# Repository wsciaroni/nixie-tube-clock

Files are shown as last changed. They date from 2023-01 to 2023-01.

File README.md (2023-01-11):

# nixie-tube-clock
Work in progress for designing and building a custom Nixie Tube Clock

## Starting Point

This project is incomplete.

I have started from the really helpful blog here: https://crystal.uta.edu/~burns/project_nixieclock.html

## Overview

I remember my first exposure to Nixie Tubes vividly. It was an old coin counting machine we were using for a change colection fund raiser. I was fascinated by the Nixie Tubes and have never forgotten them.

After observing many other Nixie Clock builds, I decided there wasn't one that met all of my needs.

The closest that I found was here: https://crystal.uta.edu/~burns/project_nixieclock.html. However, I would like a more accurate time. So, I plan to start with this project and modify it.  My goal is to

- Remove the LEDs (I don't really want a backlight)
- Change the embedded system to an ESP8266 / NodeMCU with WiFi to maintain time with the network
- Make sure the programming port is accessible so that I can reprogram or update the firmwware as needed

My Requirements for the clock are as follows

1. The clock needs to use Nixie Tubes
2. The Clock would sync with WiFi to keep a very accurate time
3. The high voltage supply's circuitry will be it's own board for modularity
4. It will be a 6 digit 24-hour clock (H1 H0 : M1 M0 : S1 S0)
5. The clock should be powered via 120V AC

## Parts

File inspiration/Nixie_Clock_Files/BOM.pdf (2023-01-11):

SCH Ref Part Name | Value or Part Number | Part Description | Mouser or Alt Link | Qty
PCB1 - HV Supply | Printed Circuit Board | High Voltage Power Supply PCB | JLCPCB.com | 1
IC1 | MC34063AP | Boost Converter IC | 595-MC34063AP (https://www.mouser.com/Search/Refine?Keyword=595-MC34063AP) | 1
IC1-SOCKET | DIP-8 Connector | DIP-8 Socket for Boost Conv. | Amazon Link (https://www.amazon.com/gp/product/B01MRZZCQU/ref=ppx_yo_dt_b_search_asin_image?ie=UTF8&psc=1) | 1
IC2 | LD1117V50 | 5V Voltage Regulator | 511-LD1117V50 (https://www.mouser.com/Search/Refine?Keyword=511-LD1117V50) | 1
Q1 | IRF630 | N-MOSFET 200V | 511-IRF630 (https://www.mouser.com/Search/Refine?Keyword=511-IRF630) | 1
Q2 | MPSA55 | PNP BJT 200V | 610-MPSA55 (https://www.mouser.com/Search/Refine?Keyword=610-MPSA55) | 1
L1 | 150uH | Inductor | 652-6100-151K-RC (https://www.mouser.com/Search/Refine?Keyword=652-6100-151K-RC) | 1
R1, R2 | 0.5Ω | 1/4W Resistor | 660-CF1/4CR50J (https://www.mouser.com/Search/Refine?Keyword=660-CF1/4CR50J) | 2
R3 | 1kΩ | 1/4W Resistor | 660-MF1/4LCT52R102J (https://www.mouser.com/Search/Refine?Keyword=660-MF1/4LCT52R102J) | 1
R4 | 13.7kΩ | 1/4W Resistor | 660-MF1/4DC1372F (https://www.mouser.com/Search/Refine?Keyword=660-MF1/4DC1372F) | 1
R5 | 475kΩ | 1/4W Resistor | 660-MF1/4DC4753F (https://www.mouser.com/Search/Refine?Keyword=660-MF1/4DC4753F) | 1
R6 | 4.02kΩ | 1/4W Resistor | 660-MF1/4DC4021F (https://www.mouser.com/Search/Refine?Keyword=660-MF1/4DC4021F) | 1
RX-POT | 50kΩ | 1/4W TrimPOT | 652-3362P-1-503LF (https://www.mouser.com/Search/Refine?Keyword=652-3362P-1-503LF) | 1
C1 | 220uF | Capacitor (Polarized Elec.) | 140-REA221M1HBK1016P (https://www.mouser.com/Search/Refine?Keyword=140-REA221M1HBK1016P) | 1
C2 | 680pF | Capacitor | 810-FG18C0G1H681JNT0 (https://www.mouser.com/Search/Refine?Keyword=810-FG18C0G1H681JNT0) | 1
C3 | 0.01uF | Capacitor | 810-FG18C0G2A103JRT6 (https://www.mouser.com/Search/Refine?Keyword=810-FG18C0G2A103JRT6) | 1
C4 | 2.2uF | Capacitor (Polarized Elec.) | 710-860021373003 (https://www.mouser.com/Search/Refine?Keyword=710-860021373003) | 1
C5 | 0.1uF | Capacitor | 810-FK18X7R1E104K (https://www.mouser.com/Search/Refine?Keyword=810-FK18X7R1E104K) | 1
C6 | 10uF | Capacitor | 810-FK16X7R1C106K (https://www.mouser.com/Search/Refine?Keyword=810-FK16X7R1C106K) | 1
D1 | BAV21 | Ultra Fast Rectifier Diode | 771-BAV21113 (https://www.mouser.com/Search/Refine?Keyword=771-BAV21113) | 1
D2 | 1N914 | Small Signal Diode | 512-1N914T50A (https://www.mouser.com/Search/Refine?Keyword=512-1N914T50A) | 1
J1, J2 | 2-Pole Connector | Screw Terminals (4 pairs total) | Amazon Link (https://www.amazon.com/gp/product/B071DN7GQ5/ref=ppx_yo_dt_b_search_asin_title?ie=UTF8&psc=1) | 4
SCH Ref Part Name | Value or Part Number | Part Description | Mouser or Alt Link | Qty
PCB2 - Nixie Clock | Printed Circuit Board | Nixie 12-Hour Clock PCB | JLCPCB.com | 1
NX1, NX2, NX3, NX4, NX5, NX6 | IN-12A | Nixie Tubes | Amazon Link (https://www.amazon.com/gp/product/B075HZBSK8/ref=ppx_yo_dt_b_search_asin_title?ie=UTF8&psc=1) | 6
NB1, NB2 | IN-3 | Nixie Bulbs (lamps) | Amazon Link (https://www.amazon.com/gp/product/B076B3WLNH/ref=ppx_yo_dt_b_search_asin_title?ie=UTF8&psc=1) | 2
IC1, IC2, IC3, IC4, IC5, IC6 | TPIC6595N | 8-Bit Shift Registers | 595-TPIC6595N (https://www.mouser.com/Search/Refine?Keyword=595-TPIC6595N) | 6
IC1-6-SOCKET | DIP-20 Connector | DIP-20 Socket for Shift Regs | 571-1-2199298-6 (https://www.mouser.com/Search/Refine?Keyword=571-1-2199298-6) | 6
IC7 | Microcontroller | PIC16F15325 | 579-PIC16F15325-I/P (https://www.mouser.com/Search/Refine?Keyword=579-PIC16F15325-I/P) | 1
IC7-SOCKET | DIP-14 Connector | DIP-14 Socket for PIC16 | 571-1-2199298-3 (https://www.mouser.com/Search/Refine?Keyword=571-1-2199298-3) | 1
IC8, IC9, IC10, IC11, IC12, IC13 | RGB | SMD LED Package | 941-CLY6DFKCCK1N1D1B (https://www.mouser.com/Search/Refine?Keyword=941-CLY6DFKCCK1N1D1B) | 6
Q1 | 12.288MHz | Crystal for PIC16 | 815-ABL-12.288-B1U (https://www.mouser.com/Search/Refine?Keyword=815-ABL-12.288-B1U) | 1
R1, R2, R3, R4, R5, R6 | 14kΩ | 1/2W Resistor | 71-CMF5514K000DHR6 (https://www.mouser.com/Search/Refine?Keyword=71-CMF5514K000DHR6) | 6
R7, R8 | 162kΩ | 1/2W Resistor | 660-MF1/2CC1623F (https://www.mouser.com/Search/Refine?Keyword=660-MF1/2CC1623F) | 2
R9, R10, R11, R12, R13, R14 | 10kΩ | 1/4W Resistor | 660-CF1/4C103J (https://www.mouser.com/Search/Refine?Keyword=660-CF1/4C103J) | 6
R15, R18 | 300Ω | 1/4W Resistor | 660-MF1/4DC3000F (https://www.mouser.com/Search/Refine?Keyword=660-MF1/4DC3000F) | 2
R16, R19 | 390Ω | 1/4W Resistor | 660-MF1/4DC3900F (https://www.mouser.com/Search/Refine?Keyword=660-MF1/4DC3900F) | 2
R17, R20 | 570Ω | 1/4W Resistor | 660-MF1/4DC5760F (https://www.mouser.com/Search/Refine?Keyword=660-MF1/4DC5760F) | 2
C1, C2, C3, C4, C5, C6, C11, C12 | 0.1uF | Capacitor | 594-K104K15X7RF53L2 (https://www.mouser.com/Search/Refine?Keyword=594-K104K15X7RF53L2) | 8
C7, C8 | 18pF | Capacitor | 810-FK18C0G1H180J (https://www.mouser.com/Search/Refine?Keyword=810-FK18C0G1H180J) | 2
C9, C10 | 0.01uF | Capacitor | 810-FG18C0G2A103JRT6 (https://www.mouser.com/Search/Refine?Keyword=810-FG18C0G2A103JRT6) | 2
POT1 | 5kΩ | Potentiometer | Amazon Link (https://www.amazon.com/gp/product/B0791GYLBZ/ref=ppx_yo_dt_b_search_asin_title?ie=UTF8&psc=1) | 1
S1 | SPST | Push Button Switch (PIC MCLR) | Amazon Link (https://www.amazon.com/gp/product/B01N76KBC6/ref=ppx_yo_dt_b_search_asin_image?ie=UTF8&psc=1) | 1
S2 | SPST | Latching Push Button Switch (Nixie Power) | Amazon Link (https://www.amazon.com/gp/product/B01DRVM3LW/ref=ppx_yo_dt_b_search_asin_title?ie=UTF8&psc=1) | 1
S3, S4, S5 | SPST | Latching Push Button Switch (LEDs) | Amazon Link (https://www.amazon.com/gp/product/B075VBV4QH/ref=ppx_yo_dt_b_search_asin_title?ie=UTF8&psc=1) | 3
ENC1 | 15mm Encoder | Rotary Encoder (with switch) | 652-PEC11R-4015F-S24 (https://www.mouser.com/Search/Refine?Keyword=652-PEC11R-4015F-S24) | 1
J1, J2, J3 | 2-Pole Connector | Screw Terminals (7 pairs total) | Amazon Link (https://www.amazon.com/gp/product/B071DN7GQ5/ref=ppx_yo_dt_b_search_asin_title?ie=UTF8&psc=1) | 7
J4 | 5-Pole Connector | Pin Header Row (5 pins) | Amazon Link (https://www.amazon.com/gp/product/B06XR8CV8P/ref=ppx_yo_dt_b_search_asin_image?ie=UTF8&psc=1) | 1

### BOM for Single High Voltage Supply PCB

### BOM for Single Nixie Clock PCB

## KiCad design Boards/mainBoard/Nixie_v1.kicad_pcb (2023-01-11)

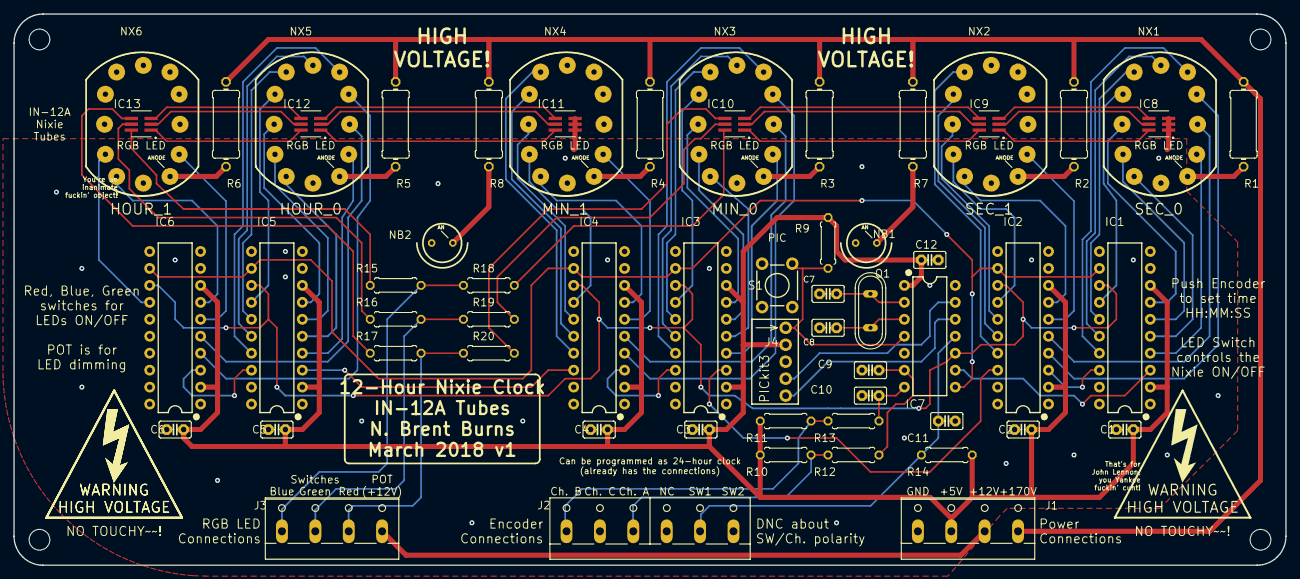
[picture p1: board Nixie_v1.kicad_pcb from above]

Board: 2 copper layers, 190.5 x 82.6 mm, 66 parts (0 on the bottom side), 96 nets.

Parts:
@HOLE0, @HOLE1, @HOLE2, @HOLE3: (no value)
C1, C2, C3, C4, C5, C6, C11, C12: 0.1uF; C2.5-2
C7, C8: 18pF; C2.5-2
C9, C10: 0.01uF; C2.5-2
IC1, IC2, IC3, IC4, IC5, IC6: TPIC6595N; DIP20
IC7: PIC16F15325; DIP14
IC8, IC9, IC10, IC11, IC12, IC13: LED-RGB_CLY6D-FKC-CK1N1D1BB7D3D3; PLCC6-LED-RGB
J1: Screw Terminal 4 Pin; SCREW_TERM_5MM_1X4
J2: CONNECTOR_6PINSCREW_TERMINAL_5MM_PITCH; SCREW_TERM_5MM_1X6
J3: RGB Switches and 5k POT Connections; SCREW_TERM_5MM_1X4
J4: PICkit 3 Programmer; HEADER_2.54MM_1X5
NB1, NB2: IN-3
NX1, NX2, NX3, NX4, NX5, NX6: NIXIE_IN-12A; IN-12_NO_HOLE
Q1: 12.288MHz; QS
R1, R2, R3, R4, R5, R6: 14k; 0411_12
R7, R8: 162k; 0411_12
R9, R10, R11, R12, R13, R14: 10k; 0207_7
R15, R18: 300; 0207_7
R16, R19: 390; 0207_7
R17, R20: 576; 0207_7
S1: !MCLR! Reset; TACTILE_SWITCH_PTH_6.0MM
SYM101: SYMBOL_HIGH_VOLTAGE
U$3, U$6: SYMBOL_HIGH_VOLTAGE

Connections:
+5V: C1.2, C2.2, C3.2, C4.2, C5.2, C6.2, C12.1, IC1.2, IC1.8, IC2.2, IC2.8, IC3.2, IC3.8, IC4.2, IC4.8, IC5.2, IC5.8, IC6.2, IC6.8, IC7.1, J1.2, J4.2, R9.2, R10.2, R11.2, R14.1
+12V: J1.3, J3.4
+170V: J1.4, R1.1, R2.1, R3.1, R4.1, R5.1, R6.1, R7.2, R8.2
GND: C1.1, C2.1, C3.1, C4.1, C5.1, C6.1, C7.2, C8.2, C9.2, C10.2, C11.1, C12.2, IC1.1, IC1.9, IC1.10, IC1.11, IC1.19, IC1.20, IC2.1, IC2.9, IC2.10, IC2.11, IC2.19, IC2.20, IC3.1, IC3.9, IC3.10, IC3.11, IC3.19, IC3.20, IC4.1, IC4.9, IC4.10, IC4.11, IC4.19, IC4.20, IC5.1, IC5.9, IC5.10, IC5.11, IC5.19, IC5.20, IC6.1, IC6.9, IC6.10, IC6.11, IC6.19, IC6.20, IC7.14, IC8.1, IC8.2, IC8.3, IC11.1, IC11.2, IC11.3, J1.1, J2.2, J2.6, J4.3, NB1.K, NB2.K, S1.3
unnamed: IC1.4, NX1.0
unnamed: IC1.5, NX1.1
unnamed: IC1.6, NX1.2
unnamed: IC1.7, NX1.3
unnamed: IC1.14, NX1.4
unnamed: IC1.15, NX1.5
unnamed: IC1.16, NX1.6
unnamed: IC1.17, NX1.7
unnamed: NX1.A, R1.2
unnamed: NB2.A, R8.1
unnamed: NX2.A, R2.2
unnamed: NB1.A, R7.1
unnamed: NX3.A, R3.2
unnamed: NX4.A, R4.2
unnamed: NX5.A, R5.2
unnamed: NX6.A, R6.2
unnamed: IC5.4, NX5.0
unnamed: IC5.5, NX5.1
unnamed: IC2.4, NX1.8
unnamed: IC2.5, NX1.9
unnamed: IC7.12, J4.5
unnamed: IC2.6, NX2.0
unnamed: IC2.7, NX2.1
unnamed: IC2.15, NX2.3
unnamed: IC2.16, NX2.4
unnamed: IC2.17, NX2.5
unnamed: IC3.4, NX3.0
unnamed: IC3.5, NX3.1
unnamed: IC3.6, NX3.2
unnamed: IC3.7, NX3.3
unnamed: IC3.14, NX3.4
unnamed: IC3.15, NX3.5
unnamed: IC3.16, NX3.6
unnamed: IC3.17, NX3.7
unnamed: IC4.4, NX3.8
unnamed: IC4.5, NX3.9
unnamed: C7.1, IC7.2, Q1.2
unnamed: C8.1, IC7.3, Q1.1
unnamed: IC7.13, J4.4
unnamed: IC4.15, NX4.3
unnamed: IC4.16, NX4.4
unnamed: IC4.17, NX4.5
unnamed: IC5.6, NX5.2
unnamed: IC5.7, NX5.3
unnamed: IC5.14, NX5.4
unnamed: IC5.15, NX5.5
unnamed: IC5.16, NX5.6
unnamed: IC5.17, NX5.7
unnamed: IC6.4, NX5.8
unnamed: IC6.5, NX5.9
unnamed: IC6.6, NX6.0
unnamed: IC6.7, NX6.1
unnamed: IC5.18, IC6.3
unnamed: IC4.18, IC5.3
unnamed: IC3.18, IC4.3
unnamed: IC2.18, IC3.3
unnamed: IC1.18, IC2.3
unnamed: IC1.12, IC2.12, IC3.12, IC4.12, IC5.12, IC6.12, IC7.8
unnamed: IC2.14, NX2.2
unnamed: IC1.13, IC2.13, IC3.13, IC4.13, IC5.13, IC6.13, IC7.10
unnamed: IC1.3, IC7.9
unnamed: IC4.14, NX4.2
unnamed: IC4.7, NX4.1
unnamed: IC4.6, NX4.0
unnamed: IC7.4, J4.1, R9.1, S1.1
unnamed: IC6.14, NX6.2
unnamed: C11.2, IC7.11, J2.5, R14.2
unnamed: C10.1, IC7.7, R13.1
unnamed: IC12.6, IC13.1
unnamed: IC11.6, IC12.1
unnamed: IC8.6, IC9.1
unnamed: IC9.6, IC10.1
unnamed: IC12.5, IC13.2
unnamed: IC11.5, IC12.2
unnamed: IC11.4, IC12.3
unnamed: IC12.4, IC13.3
unnamed: IC9.5, IC10.2
unnamed: IC8.5, IC9.2
unnamed: IC8.4, IC9.3
unnamed: IC9.4, IC10.3
unnamed: J2.3, R10.1, R12.2
unnamed: J2.1, R11.1, R13.2
unnamed: C9.1, IC7.6, R12.1
unnamed: J3.1, R15.1, R18.1
unnamed: J3.2, R16.1, R19.1
unnamed: J3.3, R17.1, R20.1
unnamed: IC13.6, R15.2
unnamed: IC13.5, R16.2
unnamed: IC13.4, R17.2
unnamed: IC10.6, R18.2
unnamed: IC10.5, R19.2
unnamed: IC10.4, R20.2

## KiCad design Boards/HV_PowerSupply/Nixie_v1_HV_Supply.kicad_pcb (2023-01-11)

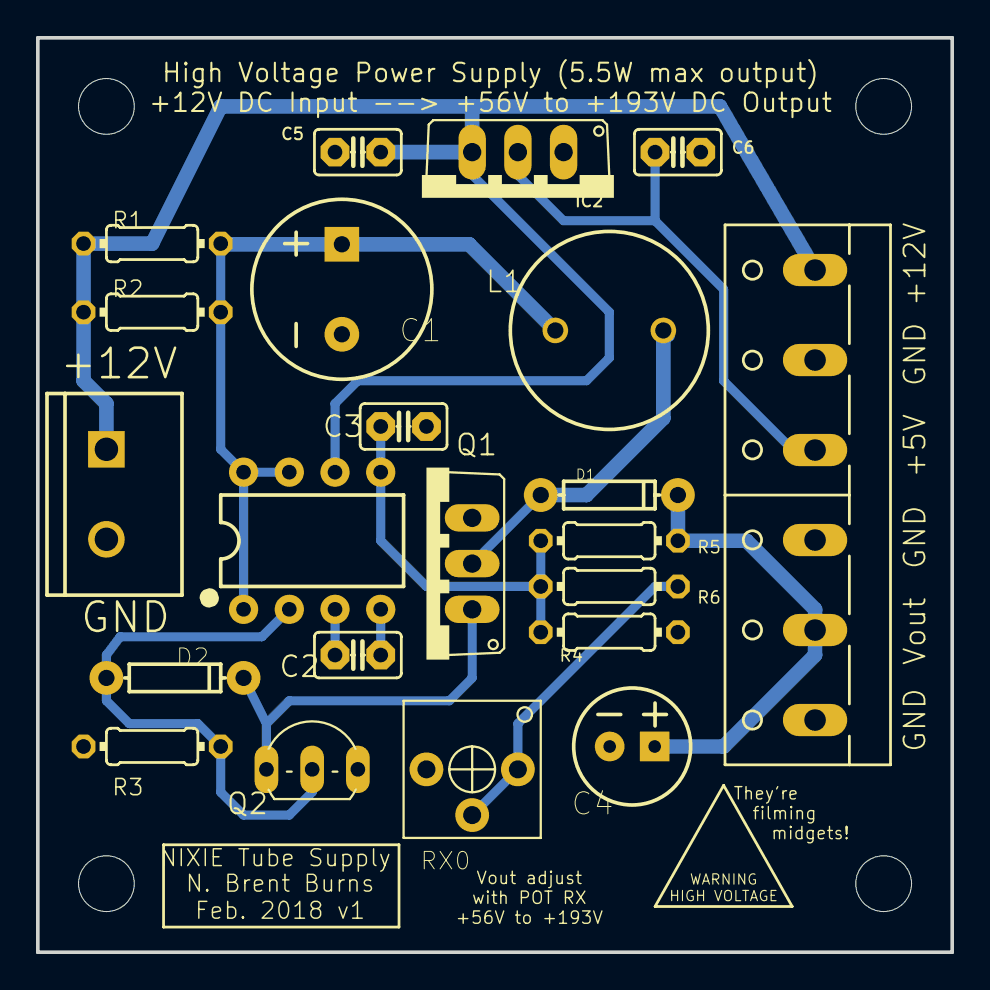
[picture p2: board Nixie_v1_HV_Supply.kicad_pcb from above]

Board: 2 copper layers, 50.8 x 50.8 mm, 26 parts (0 on the bottom side), 11 nets.

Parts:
@HOLE0, @HOLE1, @HOLE2, @HOLE3: (no value)
C1: 220uF; CPOL-RADIAL-5MM-10MM
C2: 680pF; C2.5-2
C3: 0.01uF; C2.5-2
C4: 2.2uF; CPOL-RADIAL-2.5MM-6.5MM
C5: 0.1uF; C2.5-2
C6: 10uF; C2.5-2
D1: BAV21; DIODE-1N4148
D2: 1N914; DIODE-1N4148
IC1: MC34063AP; DIP08
IC2: LD1117V50; TO220V
J1: Screw Terminal 2 Pin; SCREW_TERM_5MM_1X2
J2: Screw Terminal 6 Pin; SCREW_TERM_5MM_1X6
L1: 150uH; INDUCTOR_11MM_DIAM_6MM_PITCH
Q1: IRF630; TO220V
Q2: MPSA55; TO92-
R1, R2: 0.5; 0204_7
R3: 1k; 0204_7
R4: 13.7k; 0204_7
R5: 475k; 0204_7
R6: 4.02k; 0204_7
RX0: 50k; TRIM_POT_PTH

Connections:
GND: C1.-, C2.2, C3.2, C4.2, C5.2, C6.2, IC1.4, IC2.1, J1.2, J2.1, J2.3, J2.5, Q1.3, Q2.3, R3.1, R4.1, RX0.1
unnamed: C6.1, IC2.2, J2.4
unnamed: D1.A, L1.2, Q1.2
unnamed: C4.1, D1.C, J2.2, R5.2
unnamed: C2.1, IC1.3
unnamed: C3.1, IC1.5, R4.2, R5.1, R6.1
unnamed: C1.+, IC1.1, IC1.7, IC1.8, L1.1, R1.2, R2.2
unnamed: R6.2, RX0.2, RX0.3
unnamed: D2.A, IC1.2, Q2.2, R3.2
unnamed: D2.C, Q1.1, Q2.1
VCC: C5.1, IC1.6, IC2.3, J1.1, J2.6, R1.1, R2.1

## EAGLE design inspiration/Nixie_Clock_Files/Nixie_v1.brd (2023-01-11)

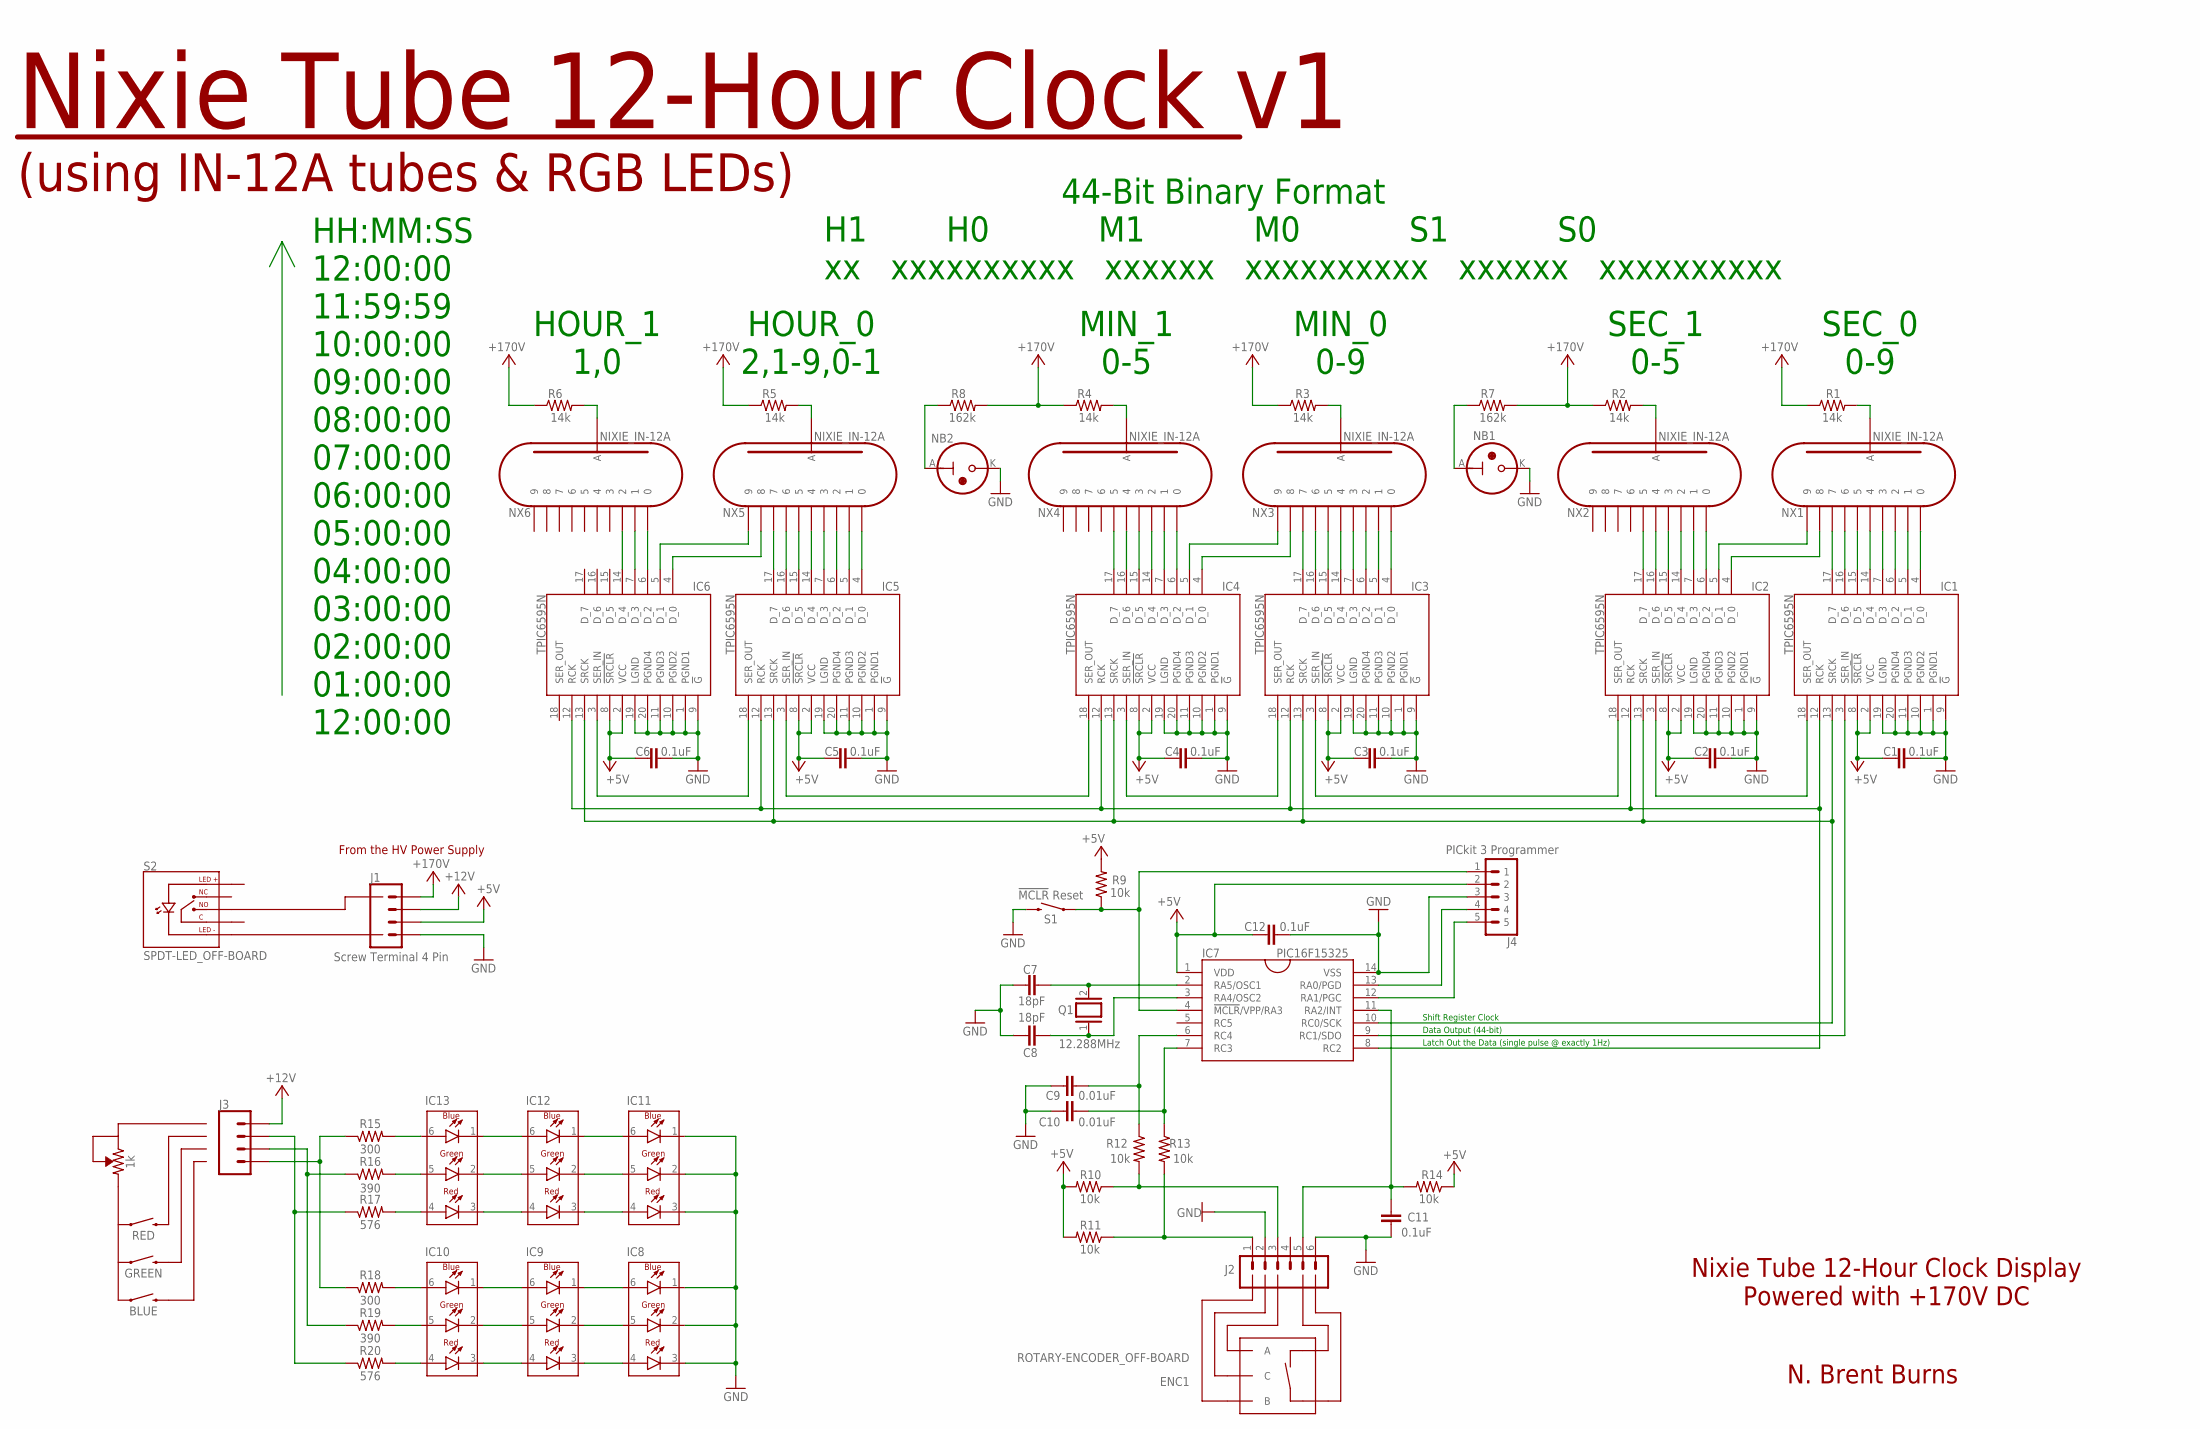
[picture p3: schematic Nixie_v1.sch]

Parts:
C1, C2, C3, C4, C5, C6, C11, C12: 0.1uF; C2.5-2
C7, C8: 18pF; C2.5-2
C9, C10: 0.01uF; C2.5-2
IC1, IC2, IC3, IC4, IC5, IC6: TPIC6595N; DIP20
IC7: PIC16F15325; DIP14
IC8, IC9, IC10, IC11, IC12, IC13: LED-RGB_CLY6D-FKC-CK1N1D1BB7D3D3; PLCC6-LED-RGB
J1: Screw Terminal 4 Pin; SCREW_TERM_5MM_1X4
J2: CONNECTOR_6PINSCREW_TERMINAL_5MM_PITCH; SCREW_TERM_5MM_1X6
J3: RGB Switches and 5k POT Connections; SCREW_TERM_5MM_1X4
J4: PICkit 3 Programmer; HEADER_2.54MM_1X5
NB1, NB2: IN-3
NX1, NX2, NX3, NX4, NX5, NX6: NIXIE_IN-12A; IN-12_NO_HOLE
Q1: 12.288MHz; QS
R1, R2, R3, R4, R5, R6: 14k; 0411/12
R7, R8: 162k; 0411/12
R9, R10, R11, R12, R13, R14: 10k; 0207/7
R15, R18: 300; 0207/7
R16, R19: 390; 0207/7
R17, R20: 576; 0207/7
S1: !MCLR! Reset; TACTILE_SWITCH_PTH_6.0MM
SYM101: SYMBOL_HIGH_VOLTAGE

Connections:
+5V: C1.2, C2.2, C3.2, C4.2, C5.2, C6.2, C12.1, IC1.2 (VCC), IC1.8 (!SRCLR), IC2.2 (VCC), IC2.8 (!SRCLR), IC3.2 (VCC), IC3.8 (!SRCLR), IC4.2 (VCC), IC4.8 (!SRCLR), IC5.2 (VCC), IC5.8 (!SRCLR), IC6.2 (VCC), IC6.8 (!SRCLR), IC7.1 (VDD), J1.2, J4.2, R9.2, R10.2, R11.2, R14.1
+12V: J1.3, J3.4
+170V: J1.4, R1.1, R2.1, R3.1, R4.1, R5.1, R6.1, R7.2, R8.2
GND: C1.1, C2.1, C3.1, C4.1, C5.1, C6.1, C7.2, C8.2, C9.2, C10.2, C11.1, C12.2, IC1.1 (PGND1), IC1.9 (!G), IC1.10 (PGND2), IC1.11 (PGND3), IC1.19 (LGND), IC1.20 (PGND4), IC2.1 (PGND1), IC2.9 (!G), IC2.10 (PGND2), IC2.11 (PGND3), IC2.19 (LGND), IC2.20 (PGND4), IC3.1 (PGND1), IC3.9 (!G), IC3.10 (PGND2), IC3.11 (PGND3), IC3.19 (LGND), IC3.20 (PGND4), IC4.1 (PGND1), IC4.9 (!G), IC4.10 (PGND2), IC4.11 (PGND3), IC4.19 (LGND), IC4.20 (PGND4), IC5.1 (PGND1), IC5.9 (!G), IC5.10 (PGND2), IC5.11 (PGND3), IC5.19 (LGND), IC5.20 (PGND4), IC6.1 (PGND1), IC6.9 (!G), IC6.10 (PGND2), IC6.11 (PGND3), IC6.19 (LGND), IC6.20 (PGND4), IC7.14 (VSS), IC8.1 (BLUE_CATHODE), IC8.2 (GREEN_CATHODE), IC8.3 (RED_CATHODE), IC11.1 (BLUE_CATHODE), IC11.2 (GREEN_CATHODE), IC11.3 (RED_CATHODE), J1.1, J2.2, J2.6, J4.3, NB1.K, NB2.K, S1.3 (2)
unnamed: IC1.4 (D_0), NX1.0
unnamed: IC1.5 (D_1), NX1.1
unnamed: IC1.6 (D_2), NX1.2
unnamed: IC1.7 (D_3), NX1.3
unnamed: IC1.14 (D_4), NX1.4
unnamed: IC1.15 (D_5), NX1.5
unnamed: IC1.16 (D_6), NX1.6
unnamed: IC1.17 (D_7), NX1.7
unnamed: NX1.A, R1.2
unnamed: NB2.A, R8.1
unnamed: NX2.A, R2.2
unnamed: NB1.A, R7.1
unnamed: NX3.A, R3.2
unnamed: NX4.A, R4.2
unnamed: NX5.A, R5.2
unnamed: NX6.A, R6.2
unnamed: IC5.4 (D_0), NX5.0
unnamed: IC5.5 (D_1), NX5.1
unnamed: IC2.4 (D_0), NX1.8
unnamed: IC2.5 (D_1), NX1.9
unnamed: IC7.12 (RA1/PGC), J4.5
unnamed: IC2.6 (D_2), NX2.0
unnamed: IC2.7 (D_3), NX2.1
unnamed: IC2.15 (D_5), NX2.3
unnamed: IC2.16 (D_6), NX2.4
unnamed: IC2.17 (D_7), NX2.5
unnamed: IC3.4 (D_0), NX3.0
unnamed: IC3.5 (D_1), NX3.1
unnamed: IC3.6 (D_2), NX3.2
unnamed: IC3.7 (D_3), NX3.3
unnamed: IC3.14 (D_4), NX3.4
unnamed: IC3.15 (D_5), NX3.5
unnamed: IC3.16 (D_6), NX3.6
unnamed: IC3.17 (D_7), NX3.7
unnamed: IC4.4 (D_0), NX3.8
unnamed: IC4.5 (D_1), NX3.9
unnamed: C7.1, IC7.2 (RA5/OSC1), Q1.2
unnamed: C8.1, IC7.3 (RA4/OSC2), Q1.1
unnamed: IC7.13 (RA0/PGD), J4.4
unnamed: IC4.15 (D_5), NX4.3
unnamed: IC4.16 (D_6), NX4.4
unnamed: IC4.17 (D_7), NX4.5
unnamed: IC5.6 (D_2), NX5.2
unnamed: IC5.7 (D_3), NX5.3
unnamed: IC5.14 (D_4), NX5.4
unnamed: IC5.15 (D_5), NX5.5
unnamed: IC5.16 (D_6), NX5.6
unnamed: IC5.17 (D_7), NX5.7
unnamed: IC6.4 (D_0), NX5.8
unnamed: IC6.5 (D_1), NX5.9
unnamed: IC6.6 (D_2), NX6.0
unnamed: IC6.7 (D_3), NX6.1
unnamed: IC5.18 (SER_OUT), IC6.3 (SER_IN)
unnamed: IC4.18 (SER_OUT), IC5.3 (SER_IN)
unnamed: IC3.18 (SER_OUT), IC4.3 (SER_IN)
unnamed: IC2.18 (SER_OUT), IC3.3 (SER_IN)
unnamed: IC1.18 (SER_OUT), IC2.3 (SER_IN)
unnamed: IC1.12 (RCK), IC2.12 (RCK), IC3.12 (RCK), IC4.12 (RCK), IC5.12 (RCK), IC6.12 (RCK), IC7.8 (RC2)
unnamed: IC2.14 (D_4), NX2.2
unnamed: IC1.13 (SRCK), IC2.13 (SRCK), IC3.13 (SRCK), IC4.13 (SRCK), IC5.13 (SRCK), IC6.13 (SRCK), IC7.10 (RC0/SCK)
unnamed: IC1.3 (SER_IN), IC7.9 (RC1/SDO)
unnamed: IC4.14 (D_4), NX4.2
unnamed: IC4.7 (D_3), NX4.1
unnamed: IC4.6 (D_2), NX4.0
unnamed: IC7.4 (!MCLR!/VPP/RA3), J4.1, R9.1, S1.1
unnamed: IC6.14 (D_4), NX6.2
unnamed: C11.2, IC7.11 (RA2/INT), J2.5, R14.2
unnamed: C10.1, IC7.7 (RC3), R13.1
unnamed: IC12.6 (BLUE_ANODE), IC13.1 (BLUE_CATHODE)
unnamed: IC11.6 (BLUE_ANODE), IC12.1 (BLUE_CATHODE)
unnamed: IC8.6 (BLUE_ANODE), IC9.1 (BLUE_CATHODE)
unnamed: IC9.6 (BLUE_ANODE), IC10.1 (BLUE_CATHODE)
unnamed: IC12.5 (GREEN_ANODE), IC13.2 (GREEN_CATHODE)
unnamed: IC11.5 (GREEN_ANODE), IC12.2 (GREEN_CATHODE)
unnamed: IC11.4 (RED_ANODE), IC12.3 (RED_CATHODE)
unnamed: IC12.4 (RED_ANODE), IC13.3 (RED_CATHODE)
unnamed: IC9.5 (GREEN_ANODE), IC10.2 (GREEN_CATHODE)
unnamed: IC8.5 (GREEN_ANODE), IC9.2 (GREEN_CATHODE)
unnamed: IC8.4 (RED_ANODE), IC9.3 (RED_CATHODE)
unnamed: IC9.4 (RED_ANODE), IC10.3 (RED_CATHODE)
unnamed: J2.3, R10.1, R12.2
unnamed: J2.1, R11.1, R13.2
unnamed: C9.1, IC7.6 (RC4), R12.1
unnamed: J3.1, R15.1, R18.1
unnamed: J3.2, R16.1, R19.1
unnamed: J3.3, R17.1, R20.1
unnamed: IC13.6 (BLUE_ANODE), R15.2
unnamed: IC13.5 (GREEN_ANODE), R16.2
unnamed: IC13.4 (RED_ANODE), R17.2
unnamed: IC10.6 (BLUE_ANODE), R18.2
unnamed: IC10.5 (GREEN_ANODE), R19.2
unnamed: IC10.4 (RED_ANODE), R20.2

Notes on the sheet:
SEC_0 0-9
SEC_1 0-5
MIN_0 0-9
MIN_1 0-5
HOUR_0 2,1-9,0-1
HOUR_1 1,0
Nixie Tube 12-Hour Clock v1
HH:MM:SS 12:00:00 11:59:59 10:00:00 09:00:00 08:00:00 07:00:00 06:00:00 05:00:00 04:00:00 03:00:00 02:00:00 01:00:00 12:00:00
(using IN-12A tubes & RGB LEDs)
Nixie Tube 12-Hour Clock Display Powered with +170V DC
N. Brent Burns
From the HV Power Supply
44-Bit Binary Format H1 H0 M1 M0 S1 S0 xx xxxxxxxxxx xxxxxx xxxxxxxxxx xxxxxx xxxxxxxxxx
Shift Register Clock
Data Output (44-bit)
Latch Out the Data (single pulse @ exactly 1Hz)

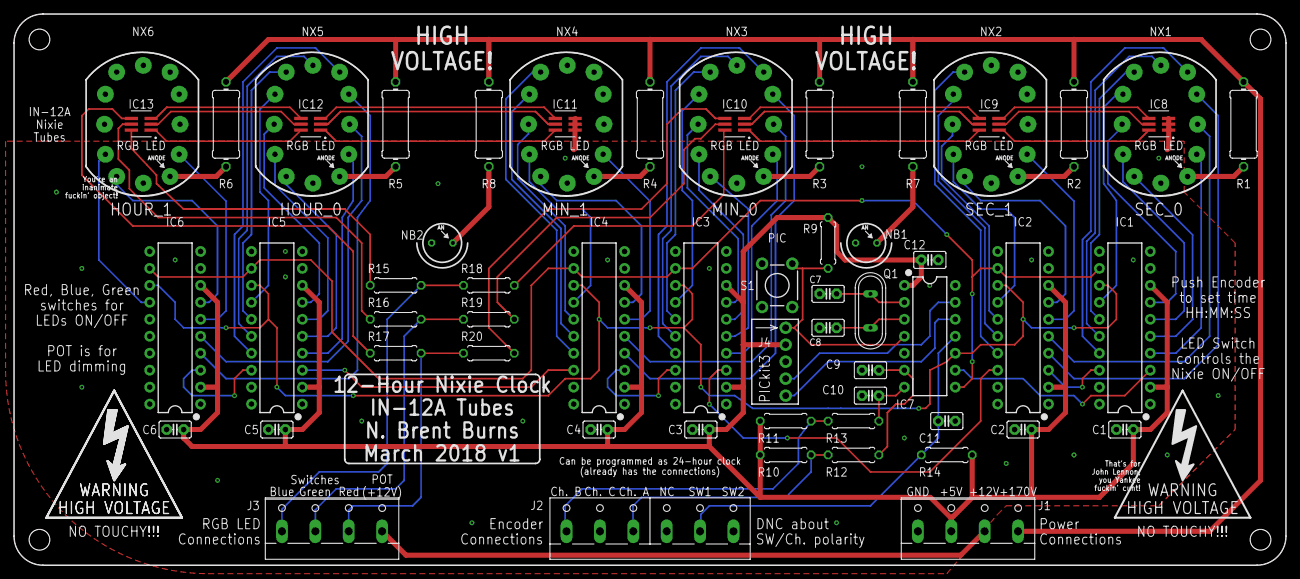
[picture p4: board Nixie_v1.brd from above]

Board: 2 copper layers, 190.5 x 82.5 mm, 62 parts (0 on the bottom side), 96 nets.

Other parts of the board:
U$3, U$6: SYMBOL_HIGH_VOLTAGE

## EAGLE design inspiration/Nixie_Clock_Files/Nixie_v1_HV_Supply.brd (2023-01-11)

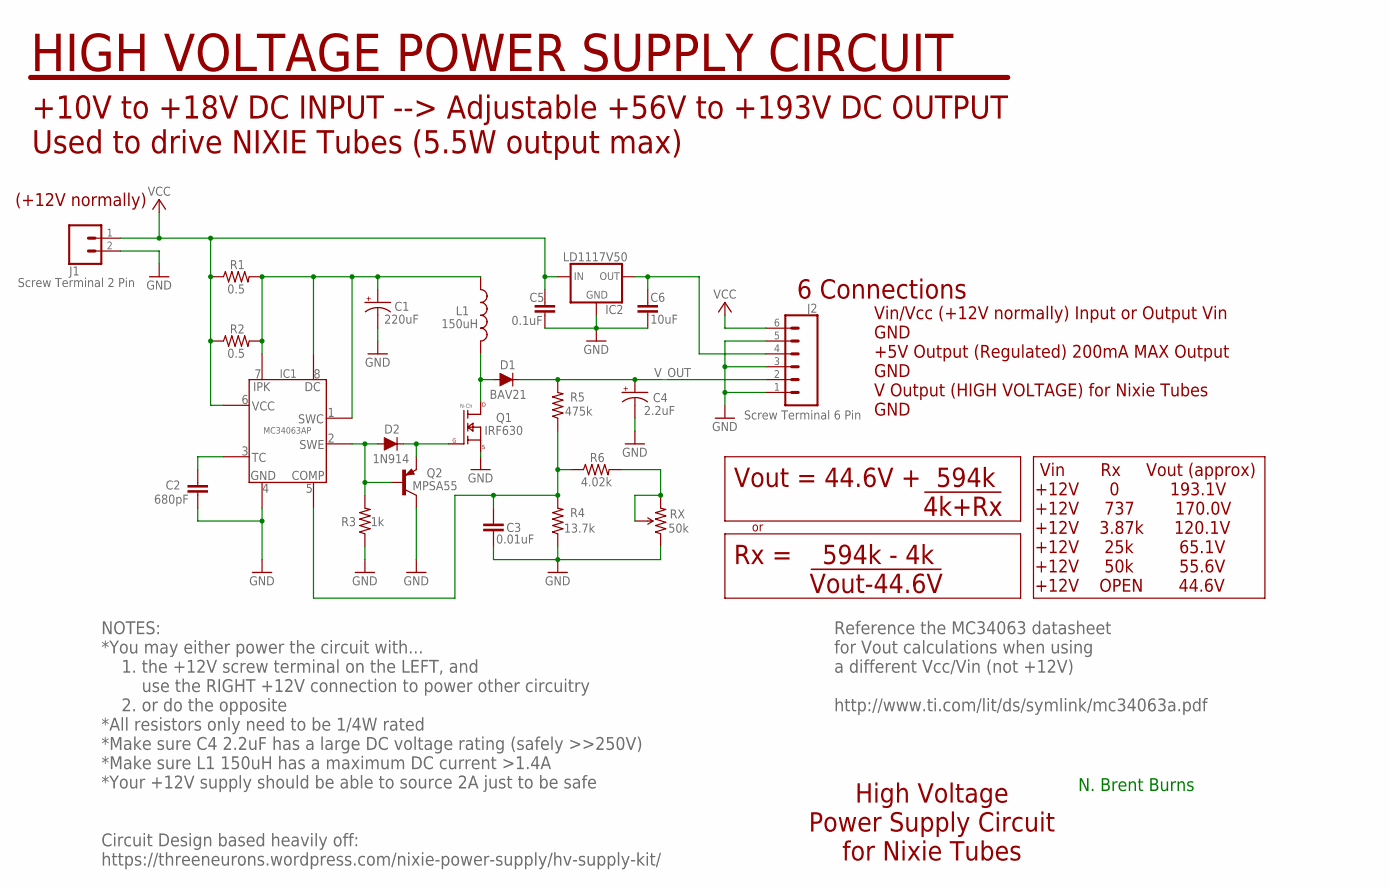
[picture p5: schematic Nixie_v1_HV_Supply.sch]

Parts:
C1: 220uF; CPOL-RADIAL-5MM-10MM
C2: 680pF; C2.5-2
C3: 0.01uF; C2.5-2
C4: 2.2uF; CPOL-RADIAL-2.5MM-6.5MM
C5: 0.1uF; C2.5-2
C6: 10uF; C2.5-2
D1: BAV21; DIODE-1N4148
D2: 1N914; DIODE-1N4148
IC1: MC34063AP; DIP08
IC2: LD1117V50; TO220V
J1: Screw Terminal 2 Pin; SCREW_TERM_5MM_1X2
J2: Screw Terminal 6 Pin; SCREW_TERM_5MM_1X6
L1: 150uH; INDUCTOR_11MM_DIAM_6MM_PITCH
Q1: IRF630; TO220V
Q2: MPSA55; TO92-
R1, R2: 0.5; 0204/7
R3: 1k; 0204/7
R4: 13.7k; 0204/7
R5: 475k; 0204/7
R6: 4.02k; 0204/7
RX: 50k; TRIM_POT_PTH

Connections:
GND: C1.-, C2.2, C3.2, C4.2 (-), C5.2, C6.2, IC1.4 (GND), IC2.1 (GND), J1.2, J2.1, J2.3, J2.5, Q1.3 (SOURCE), Q2.3 (C), R3.1, R4.1, RX.1 (CCW)
unnamed: C6.1, IC2.2 (OUT), J2.4
unnamed: D1.A, L1.2, Q1.2 (DRAIN)
unnamed: C4.1 (+), D1.C, J2.2, R5.2
unnamed: C2.1, IC1.3 (TC)
unnamed: C3.1, IC1.5 (COMP), R4.2, R5.1, R6.1
unnamed: C1.+, IC1.1 (SWC), IC1.7 (IPK), IC1.8 (DC), L1.1, R1.2, R2.2
unnamed: R6.2, RX.2 (WIPER), RX.3 (CW)
unnamed: D2.A, IC1.2 (SWE), Q2.2 (B), R3.2
unnamed: D2.C, Q1.1 (GATE), Q2.1 (E)
VCC: C5.1, IC1.6 (VCC), IC2.3 (IN), J1.1, J2.6, R1.1, R2.1

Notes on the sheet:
High Voltage Power Supply Circuit for Nixie Tubes
N. Brent Burns
HIGH VOLTAGE POWER SUPPLY CIRCUIT
+10V to +18V DC INPUT --> Adjustable +56V to +193V DC OUTPUT Used to drive NIXIE Tubes (5.5W output max)
V_OUT
Vin/Vcc (+12V normally) Input or Output Vin GND +5V Output (Regulated) 200mA MAX Output GND V Output (HIGH VOLTAGE) for Nixie Tubes GND
6 Connections
NOTES: *You may either power the circuit with... 1. the +12V screw terminal on the LEFT, and use the RIGHT +12V connection to power other circuitry 2. or do the opposite *All resistors only need to be 1/4W rated *Make sure C4 2.2uF has a large DC voltage rating (safely >>250V) *Make sure L1 150uH h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
Vout = 44.6V + 594k !4k+Rx!
Vin Rx Vout (approx) +12V 0 193.1V +12V 737 170.0V +12V 3.87k 120.1V +12V 25k 65.1V +12V 50k 55.6V +12V OPEN 44.6V
Rx = 594k - 4k !Vout-44.6V!
Circuit Design based heavily off: https://threeneurons.wordpress.com/nixie-power-supply/hv-supply-kit/
(+12V normally)
Reference the MC34063 datasheet for Vout calculations when using a different Vcc/Vin (not +12V) http://www.ti.com/lit/ds/symlink/mc34063a.pdf

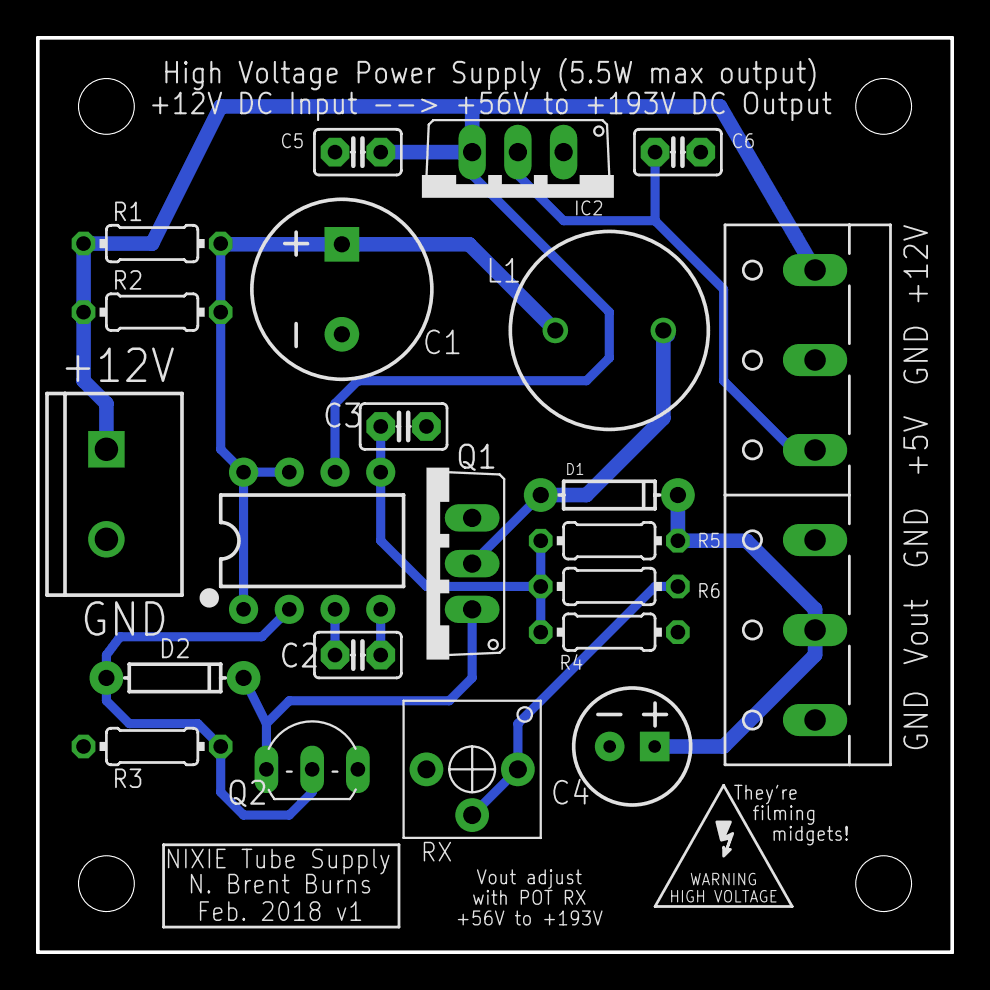
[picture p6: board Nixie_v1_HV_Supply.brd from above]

Board: 1 copper layer, 50.8 x 50.8 mm, 22 parts (0 on the bottom side), 11 nets.

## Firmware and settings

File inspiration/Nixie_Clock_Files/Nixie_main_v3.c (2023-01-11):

/*
 * File:        Nixie_main.c
 * Author:      N. Brent Burns
 * Compiler:    XC8 v1.43
 * 
 * Started: February 25, 2018, 9:33 PM (while drunk)
 * 
 * Info:    This .C code is for a 12-Hour Nixie Tube Clock circuit.
 *          This PIC determines/controls/outputs the accurate 1Hz clock signal. 
 *          It also correctly determines and feeds time display values to the shift registers (logic-level). 
 * 
 *          Originally started with a 40-pin PIC18F4520
 *              but switched to a 14-pin PIC16F15325 to reduce overall pin count/size.
 * 
 *          Need an external crystal for final design (way more fucking accurate). 
 *          This code needs to produce a 44-bit number (to send out Sync. serially)
 *              to represent the time of a 12-hour clock (H1H0:M1M0:S1S0), details below. 
 *
 *          If you want a 24-hour clock, you have to rework the code and
 *              output a 45-bit number (to account for the additional digit of H1)
 * 
 *          Full details of this project (circuit/SCH/PCB/etc.) can be found at:
 *              "Projects" tab at http://crystal.uta.edu/~burns/
 * 
 *          This project was inspired by (straight up stolen from honestly):
 *              Threeneuron: https://threeneurons.files.wordpress.com/2015/08/hv_supply_kit.pdf
 *                  for the High Voltage Power Supply for my Nixie Circuit
 *              Dave Jones (EEVblog): https://www.youtube.com/watch?v=7uogKucrPks&list=PLvOlSehNtuHutdg1kZkG7aAYhjoJnk2fc
 *                  for the general design of driving (logically) the Nixe Tubes
 */

/*
 * DETAILED NOTES:  
 * 
 * Want a 12-hour clock format
 * 12hr x 60min x 60sec = 43,200 dec (use a single global var to store this value, unsigned int of 16 bits will do)
 * 44-bit binary format for shift registers (H1H0:M1M0:S1S0): 
 *            H1: 1,0   H0: 2,1-9,0,1   M1: 0-5   M0: 0-9   S1: 0-5   S0: 0-9           (decimal digits)
 *              H1           H0           M1        M0        S1        S0
 *      (MSB)   xx       xxxxxxxxxx    xxxxxx   xxxxxxxxxx  xxxxxx  xxxxxxxxxx   (LSB)  (take up this many binary bits)
 * 
 * Need to serially shift out this 44-bit number 8-bits at a time
 * 
 * One-way communication PIC-->Shift Registers
 * Use the sync. SPI module of the PIC18
 * 
 * PIC16F15325 Pins         TPIC6595 Shift Register Pins/Buses
 *  SCK (pin 10)---------------SRCK   (clock for shifting out serial (binary) data, 44 HIGH-to-LOW pulses, idle low, rising edge data out/in)
 *                                     max frequency: 50MHz (I think), aim much slower, but still much faster than 1Hz to beat the actual clock display
 *  SDO (pin 9)----------------SER_IN (actual binary data output, 44 bits)
 *  C2  (pin 8)----------------RCK    (single clock pulse (idle low, pulse HIGH-to-LOW) to latch in all shifted data at once)
 *                                     this RCK needs to happen every 1sec (EXACTLY)
 * 
 * PIC16F15325 Pins         Rotary Encoder Connections
 *  INT/RA2 (pin 11)---------------Push Button  (Normally pulled HIGH via resistor, pulsed LOW when user pressed the encoder's push button)
 *                                              (used as an External Interrupt to toggle through User Set Mode to adjust the clock's time)
 *  RC4 (pin 6)--------------------Channel A    (Ch. A and B used together to get direction (inc/dec) and adjust time when the user rotates the encoder)
 *  RC3 (pin 7)--------------------Channel B    (User must have previously pressed the Push Button for the rotation to adjust the time)
 *                                     
 * 
 * General structure (Free Running Mode):
 *      1. Calculate current time vars (H1H0:M1M0:S1S0)
 *      2. Encode each var into the correct binary format
 *      3. Combine into one/two/three binary numbers to send out serially
 *      4. Load binary number(s), start SRCK, binary number(s) are outputted to shift registers
 *      5. Stop SRCK when last bit goes out
 *      6. When 1sec (1Hz) timer interrupt goes off, pulse the RCK (latches the shift registers, Nixie tubes show new numbers)
 *      7. Increment the current time vars
 *      8. Go back to step 1
 * 
 * General structure (User Set Mode): 
 *      1. External INT pin interrupt connected to the Push Button switch of the Rotary Encoder
 *      2. This push action cycles through individually adjusting (inc/dec) the HOURS, MINS, and then SECS
 *      3. One more push puts the clock back into normal Free Running Mode, starting off wherever you adjusted to
 *      4. The rotary encoder increments/decrements individual digit segments and updates in real-time (as instant as possible)
 */

// PIC16F15325 Configuration Bit Settings
// 'C' source line config statements
#pragma config FEXTOSC = HS       // External Oscillator mode selection bits (HS (crystal oscillator) above 4MHz; PFM set to high power)
#pragma config RSTOSC = EXT1X     // Power-up default value for COSC bits (EXTOSC operating per FEXTOSC bits)
#pragma config CLKOUTEN = OFF     // Clock Out Enable bit (CLKOUT function is disabled; i/o or oscillator function on OSC2)
#pragma config CSWEN = ON         // Clock Switch Enable bit (Writing to NOSC and NDIV is allowed)
#pragma config FCMEN = OFF        // Fail-Safe Clock Monitor Enable bit (FSCM timer disabled)
#pragma config MCLRE = ON         // Master Clear Enable bit (MCLR pin is Master Clear function)
#pragma config PWRTE = OFF        // Power-up Timer Enable bit (PWRT disabled)
#pragma config LPBOREN = OFF      // Low-Power BOR enable bit (ULPBOR disabled)
#pragma config BOREN = OFF        // Brown-out reset enable bits (Brown-out reset disabled)
#pragma config BORV = LO          // Brown-out Reset Voltage Selection (Brown-out Reset Voltage (VBOR) set to 1.9V on LF, and 2.45V on F Devices)
#pragma config ZCD = OFF          // Zero-cross detect disable (Zero-cross detect circuit is disabled at POR.)
#pragma config PPS1WAY = OFF      // Peripheral Pin Select one-way control (The PPSLOCK bit can be set and cleared repeatedly by software)
#pragma config STVREN = OFF       // Stack Overflow/Underflow Reset Enable bit (Stack Overflow or Underflow will not cause a reset)
#pragma config WDTCPS = WDTCPS_31 // WDT Period Select bits (Divider ratio 1:65536; software control of WDTPS)
#pragma config WDTE = OFF         // WDT operating mode (WDT Disabled, SWDTEN is ignored)
#pragma config WDTCWS = WDTCWS_7  // WDT Window Select bits (window always open (100%); software control; keyed access not required)
#pragma config WDTCCS = SC        // WDT input clock selector (Software Control)
#pragma config BBSIZE = BB512     // Boot Block Size Selection bits (512 words boot block size)
#pragma config BBEN = OFF         // Boot Block Enable bit (Boot Block disabled)
#pragma config SAFEN = OFF        // SAF Enable bit (SAF disabled)
#pragma config WRTAPP = OFF       // Application Block Write Protection bit (Application Block not write protected)
#pragma config WRTB = OFF         // Boot Block Write Protection bit (Boot Block not write protected)
#pragma config WRTC = OFF         // Configuration Register Write Protection bit (Configuration Register not write protected)
#pragma config WRTSAF = OFF       // Storage Area Flash Write Protection bit (SAF not write protected)
#pragma config LVP = OFF          // Low Voltage Programming Enable bit (High Voltage on MCLR/Vpp must be used for programming)
#pragma config CP = OFF           // UserNVM Program memory code protection bit (UserNVM code protection disabled)

#include <xc.h>
#include <math.h>

#define _XTAL_FREQ 12288000 // Fosc = 12.288MHz (external crystal)

#define RCK_Latch_Signal    PORTCbits.RC2 // output IO pulse to latch out Shift Register data
#define Encoder_Ch_A        PORTCbits.RC4 // input from Channel A of the Encoder (RPG)
#define Encoder_Ch_B        PORTCbits.RC3 // input from Channel B of the Encoder (RPG)

#define MODE_FREE_RUNNING   0   // clock increments freely and normally
#define MODE_EDIT_HOURS     1   // user can use the encoder to select/adjust HOURS digits
#define MODE_EDIT_MINS      2   // user can use the encoder to select/adjust MINUTES digits
#define MODE_EDIT_SECS      3   // user can use the encoder to select/adjust SECONDS digits

unsigned char currentMode = 0;  // 4 different modes the clock can be in (incremented by the push button of the encoder)
unsigned int myTime = 0;        // 0 to 43,200 decimal (12hr x 60min x 60sec = 43,200)
unsigned char waitFlag = 0;     // set in the timer ISR, used in main() to prevent unnec. time calculations

// Function Prototypes
void interrupt ISR_High(void);
void sendDataOut(void);
void latchOutData(void);

void main(void) 
{
    unsigned char i = 0;
    unsigned char aState_curr = 0;
    unsigned char aState_prev = 0;
    unsigned char adjustSecs = 0;  // only valid values 0-59
    unsigned char adjustMins = 0;  // only valid values 0-59
    unsigned char adjustHours = 0; // only valid values 1-12, but remember 12 truly means 0
    
    ANSELA = 0; // all digital I/O (no analog inputs)
    ANSELC = 0; // all digital I/O (no analog inputs)
    
    // TRIS I/O Settings
    //      C5 = Don't Care (or output testing BLUE_LED)
    //      C4 = Input for Encoder Channel A
    //      C3 = Input for Encoder Channel B
    //      C2 = Output for RCK Data Latch Output Pulse to shift registers
    //      C1 = SPI SDO 44-bit serial output data (SER_IN) to shift registers
    //      C0 = SPI Clock for the SRCK serial clock to shift registers
    TRISC = 0b011000;
    TRISA = 0b111111; //All inputs, OSC pins, Ext. INT, etc.
    
    // Turn off everything in the beginning
    RCK_Latch_Signal = 0;
    PORTCbits.RC0 = 0; // SCK/SCL
    PORTCbits.RC1 = 0; // SDO
    
    // PPS Settings (Peripheral Pin Select) (mapping)
    // want SDO on Pin 9 (RC1) & SCK on Pin 10 (RC0)
    RC0PPS = 0x15;   // RC0->MSSP1:SCK1;
    RC1PPS = 0x16;   // RC1->MSSP1:SDO1;
    
    // SPI settings (to send data/clock to the shift registers)
    SSP1CON1bits.SSPEN  = 1; // Just turn ON and leave on
    SSP1STATbits.CKE    = 1; // IDLE state is LOW (0), data transmitted out on rising edge of SCK
    SSP1CON1bits.SSPM3  = 0; // 0010 SPI Clock = Fosc/64
    SSP1CON1bits.SSPM2  = 0; // 0010 SPI Clock = Fosc/64
    SSP1CON1bits.SSPM1  = 1; // 0010 SPI Clock = Fosc/64
    SSP1CON1bits.SSPM0  = 0; // 0010 SPI Clock = Fosc/64
    
    // Clear all the outputs of the shift registers (turn off all Nixies)
    for(i=0; i<6; i++)
    {
        SSP1BUF = 0b00000000; // 6 x 8 bits for all the shift register outputs
        while(SSP1STATbits.BF == 0);
    }
    
    // Latch everything out of the shift registers all at once
    latchOutData();
    
    // Timer settings (to generate the exact 1Hz Nixie clock latch signal)
    /**
     * d = 1.0sec
     * Fosc = 12.288MHz = 12,288,000 Hz
     * Fin = Fosc / 4 = 12.288MHz / 4 = 3.072MHz
     * 
     * Using 16-bit mode (0-65,535)
     * Use prescaler 1:64 and postscaler 1:1 to fit into 16-bit register (<65k)
     * 
     * 3,072,000 / 64 / 1 = 48,000
     * Preload = 65,536 - 48,000 = 17,536 = 0x4480
     */
    
    T0CON0bits.T0EN     = 0; // timer0 off for the moment
    T0CON0bits.T016BIT  = 1; // 16-bit timer0 mode
    T0CON0bits.T0OUTPS3 = 0; // 0000 1:1 postscaler (no postscaler)
    T0CON0bits.T0OUTPS2 = 0; // 0000 1:1 postscaler (no postscaler)
    T0CON0bits.T0OUTPS1 = 0; // 0000 1:1 postscaler (no postscaler)
    T0CON0bits.T0OUTPS0 = 0; // 0000 1:1 postscaler (no postscaler)
    
    T0CON1bits.T0CS2 = 0;   // 010 Timer0 clock source = Fosc/4
    T0CON1bits.T0CS1 = 1;   // 010 Timer0 clock source = Fosc/4
    T0CON1bits.T0CS0 = 0;   // 010 Timer0 clock source = Fosc/4
    T0CON1bits.T0ASYNC = 0; // sync. timer0 counter with Fosc/4 (why the fuck not)
    T0CON1bits.T0CKPS3 = 0; // 0110 1:64 prescaler
    T0CON1bits.T0CKPS2 = 1; // 0110 1:64 prescaler
    T0CON1bits.T0CKPS1 = 1; // 0110 1:64 prescaler
    T0CON1bits.T0CKPS0 = 0; // 0110 1:64 prescaler
    
    TMR0H = 0x44; // preload value = 0x4480 (LOAD HIGH FIRST!!!)
    TMR0L = 0x80; // preload value = 0x4480
    
    // Interrupt settings (1Hz timer0 interrupt, external switch interrupt)
    PIE0bits.TMR0IE = 1;    // enable timer0 interrupt
    INTCONbits.INTEDG = 1;  // INT rising edge triggered from PB Switch of the Encoder
    PIE0bits.INTE = 1;      // enable external INT interrupt
    PIR0bits.INTF = 0;
    INTCONbits.PEIE = 1;
    INTCONbits.GIE  = 1;
    
    T0CON0bits.T0EN = 1;   // start timer0

    // main routine while loop
    while(1)
    {
        while(currentMode == MODE_FREE_RUNNING)
        {
            if(waitFlag == 0) // Only do if ready, don't perform unnec. calculations
            {
                sendDataOut();
                waitFlag = 1;
            }
        }
        
        // User Set Mode: Adjust the Hours Digits of the Clock
        while(currentMode == MODE_EDIT_HOURS)
        {
            // Read the Encoder (might make it function-based later)
            aState_curr = PORTCbits.RC4; // Encoder Channel A output

            if(aState_curr != aState_prev) // Did a rotation occur?
            {
                adjustHours = myTime / 3600; // Starting point for Hours adjustment (find the current H1:H0)
                
                if(aState_curr != PORTCbits.RC3) // Compare Ch. A vs B, CW or CCW?, increment or decrement?
                {
                    adjustHours++;
                    
                    // weird case, "adjusting" a 0 to a 12 is done in sendDataOut()
                    if(adjustHours >= 12) // want the incrementing to be cyclical
                        adjustHours = 0;
                }
                else
                {
                    adjustHours--;
                    
                    // weird case again, if decrement lower than zero (rollover to high int value)
                    if(adjustHours >= 13) // want the decrementing to be cyclical
                        adjustHours = 11;
                }

                // could combine these next two lines together, but it's a little more clear this way
                myTime = myTime - ((myTime / 3600)*3600); // subtract all the possible hours from the overall time
                myTime = myTime + (adjustHours*3600);     // add back the new adjusted hours to the overall time
                
                sendDataOut();

                // Latch everything out of the shift registers all at once
                latchOutData();

                aState_prev = aState_curr;
            }
        }
        
        // User Set Mode: Adjust the Minutes Digits of the Clock
        while(currentMode == MODE_EDIT_MINS)
        {
            // Read the Encoder (might make it function-based later)
            aState_curr = PORTCbits.RC4; // Encoder Channel A output

            if(aState_curr != aState_prev) // Did a rotation occur?
            {
                adjustMins = (myTime / 60) % 60; // Starting point for Minutes adjustment  (find the current M1:M0)
                
                if(aState_curr != PORTCbits.RC3) // Compare Ch. A vs B, CW or CCW?, increment or decrement?
                {
                    adjustMins++;
                    
                    if(adjustMins >= 60) // want the incrementing to be cyclical
                        adjustMins = 0;
                }
                else
                {
                    adjustMins--;
                    
                    if(adjustMins >= 60) // want the decrementing to be cyclical
                        adjustMins = 59;
                }

                myTime = myTime - (((myTime / 60) % 60) * 60); // subtract all the possible minutes from the overall time
                myTime = myTime + (adjustMins*60);           // add back the new adjusted minutes to the overall time
                
                sendDataOut();

                // Latch everything out of the shift registers all at once
                latchOutData();

                aState_prev = aState_curr;
            }
        }
        
        // User Set Mode: Adjust the Seconds Digits of the Clock
        while(currentMode == MODE_EDIT_SECS)
        {
            // Read the Encoder (might make it function-based later)
            aState_curr = PORTCbits.RC4; // Encoder Channel A output
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
} // end of void main(void)



// HIGH Priority Interrupt Service Routine
void interrupt ISR_High(void)
{
    // Was the 1Hz TIMER0 interrupt triggered?
    if((PIE0bits.TMR0IE == 1) && (PIR0bits.TMR0IF == 1))
    {
        // reload the preload value immediately, CRUCIAL!!!
        TMR0H = 0x44; // preload value = 0x4480 (LOAD HIGH FIRST!!!)
        TMR0L = 0x80; // preload value = 0x4480
    
        // Latch everything out of the shift registers all at once
        latchOutData();
        
        myTime++;
        waitFlag = 0;
        PIR0bits.TMR0IF = 0;  // Clear flag
    }
    
    // Was the PB Switch of the Encoder pushed?
    if((PIE0bits.INTE == 1) && (PIR0bits.INTF == 1))
    {
//        __delay_ms(10);
        PIE0bits.TMR0IE = 0;   // temp. disable the timer0 interrupt
        T0CON0bits.T0EN = 0;   // pause/stop timer0
        PIR0bits.TMR0IF = 0;
        
        
        currentMode++;
        
        if(currentMode >= 4)
            currentMode = 0;

        PIR0bits.INTF = 0;
        
        if(currentMode == MODE_FREE_RUNNING) // in free-running mode, want timer to increment clock normally at 1Hz
        {
            // reload the preload value immediately, CRUCIAL!!!
            TMR0H = 0x44; // preload value = 0x4480 (LOAD HIGH FIRST!!!)
            TMR0L = 0x80; // preload value = 0x4480
            PIE0bits.TMR0IE = 1;    // re-enable timer0 interrupt
            T0CON0bits.T0EN = 1;    // restart timer0
        }  
    }
}

void sendDataOut(void)
{
    // Temp time calculation variables
    unsigned int hours = 0;
    unsigned int mins  = 0;
    unsigned int secs  = 0;
    unsigned int h1    = 0;
    unsigned int h0    = 0;
    unsigned int m1    = 0;
    unsigned int m0    = 0;
    unsigned int s1    = 0;
    unsigned int s0    = 0;

    // Vars for the final weird binary format for the shift registers 
    unsigned int bin_hour1 = 0;
    unsigned int bin_hour0 = 0;
    unsigned int bin_min1  = 0;
    unsigned int bin_min0  = 0;
    unsigned int bin_sec1  = 0;
    unsigned int bin_sec0  = 0;

    // Disable external INT when doing stuff below so INT0 user switch
    // doesn't interrupt during a crucial time
    PIE0bits.INTE = 0;
            
    // STEP 1
    // Split the myTime (total seconds) var into hours, minutes, seconds
    // and then split each once more to extract the individual digits

    if(myTime >= 43200) // 12 hours expressed in 43,200 seconds
        myTime = 0;     // reset the clock counter var

    // HH:MM:SS encoding (12-hour format, no AM/PM)
    // H1 H0 : M1 M0 : S1 S0    (more detailed)

    secs = myTime % 60;
    s1 = secs / 10; 
    s0 = secs % 10;

    mins = (myTime / 60) % 60;
    m1 = mins / 10;
    m0 = mins % 10;

    hours = myTime / 3600;

    if(hours == 0) //special case
        hours = 12;

    h1 = hours / 10;
    h0 = hours % 10;

    // STEP 2
    // Encode/format the above vars into the "odd" binary output for shift registers
    // For each individual binary number, only a single bit may be HIGH (1)

    // 44-bit binary format for shift registers (H1H0:M1M0:S1S0): 
    //      H1: 1,0   H0: 2,1-9,0,1   M1: 0-5   M0: 0-9   S1: 0-5   S0: 0-9
    //         H1           H0           M1        M0        S1        S0
    // (MSB)   xx       xxxxxxxxxx    xxxxxx   xxxxxxxxxx  xxxxxx  xxxxxxxxxx   (LSB)

    //                          H1H0    H0      M1 |M0    M0     S1  |S0    S0
    // More Detailed: (MSB) 0000xxxx xxxxxxxx xxxxxxxx xxxxxxxx xxxxxxxx xxxxxxxx  (LSB)
    // Have to send out in 8-bit chunks

    // Need to serially shift out this 44-bit number 8-bits at a time
    // Send out starting with the MSB side (hours side)

    // encode and send data out serially 
    // (but not displayed yet, that's in the Timer ISR which calls latchOutData() and pulses the RCK pin)
    bin_hour1 = (unsigned int)pow(2,h1); //0-bit of shiftReg is connected to Nixie "0", and logically so on...
    bin_hour0 = (unsigned int)pow(2,h0);
    bin_min1  = (unsigned int)pow(2,m1);
    bin_min0  = (unsigned int)pow(2,m0);
    bin_sec1  = (unsigned int)pow(2,s1);
    bin_sec0  = (unsigned int)pow(2,s0);

    // might need to wrap this stuff with all interrupts disabled to be safe
    SSP1BUF = 0b00001111 & (((bin_hour1<<2)&0b1100) | ((bin_hour0>>8)&0b11));
    while(SSP1STATbits.BF == 0);

    SSP1BUF = bin_hour0;
    while(SSP1STATbits.BF == 0);

    SSP1BUF = ((bin_min1<<2)&0b11111100) | ((bin_min0>>8)&0b11);
    while(SSP1STATbits.BF == 0);

    SSP1BUF = bin_min0;
    while(SSP1STATbits.BF == 0);

    SSP1BUF = ((bin_sec1<<2)&0b11111100) | ((bin_sec0>>8)&0b11);
    while(SSP1STATbits.BF == 0);

    SSP1BUF = bin_sec0;
    while(SSP1STATbits.BF == 0);
    
    // Re-Enable the external INT when waiting
    PIE0bits.INTE = 1;
}

void latchOutData(void)
{
    // Disable external INT when doing stuff below so INT0 user switch
    // doesn't interrupt during a crucial time
    PIE0bits.INTE = 0;
    
    // Pulse RCK, idle LOW then HIGH-LOW pulse
    // fool around with how fast I can do this
    // Latch everything out of the shift registers all at once
    RCK_Latch_Signal = 1;
    __delay_ms(10);
    RCK_Latch_Signal = 0;
    
    // Re-Enable the external INT when waiting
    PIE0bits.INTE = 1;
}

// end of Nixie_main.c (peace)

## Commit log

2023-01-11 Add Starting Project files
    [BOM.xlsx, Nixie_v1.brd, Nixie_v1.sch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]
2023-01-11 Import Boards into KiCad from EAGLE
    [Nixie_v1.kicad_pcb, Nixie_v1.kicad_sch, Nixie_v1_HV_Supply.kicad_pcb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]
2023-01-11 Remove unused symbols from Schematic
    [Nixie_v1.kicad_sch]

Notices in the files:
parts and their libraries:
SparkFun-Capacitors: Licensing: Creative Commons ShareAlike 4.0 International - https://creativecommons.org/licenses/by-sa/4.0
